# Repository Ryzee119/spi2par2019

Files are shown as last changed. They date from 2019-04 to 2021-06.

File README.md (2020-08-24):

# spi2par2019
  
## What is it?
This is a recreation of a legacy Original Xbox adaptor that allowed you to use extremely common and cheap HD44780 compliant character LCD displays with the Xenium modchip SPI interface. The legacy adaptor was called 'spi2par' and has long since been out of production and extremely hard to come by.

I have never had one either, so this design has been made from the ground up.

There are two PCB layouts in this repository:

1. More faithful to the legacy spi2par design.
2. An LCD backpack design that takes advantage of the standard pinout of most HD44780 LCD displays to minimise the amount of wiring needed.

These two layouts are shown in the below photo. The LCD backpack has two pin arrangements so can be used on the two common LCD pin header layouts as shown installed. The intent is to make this as open and easily accessible to anyone with minimal experience in soldering and programming.  
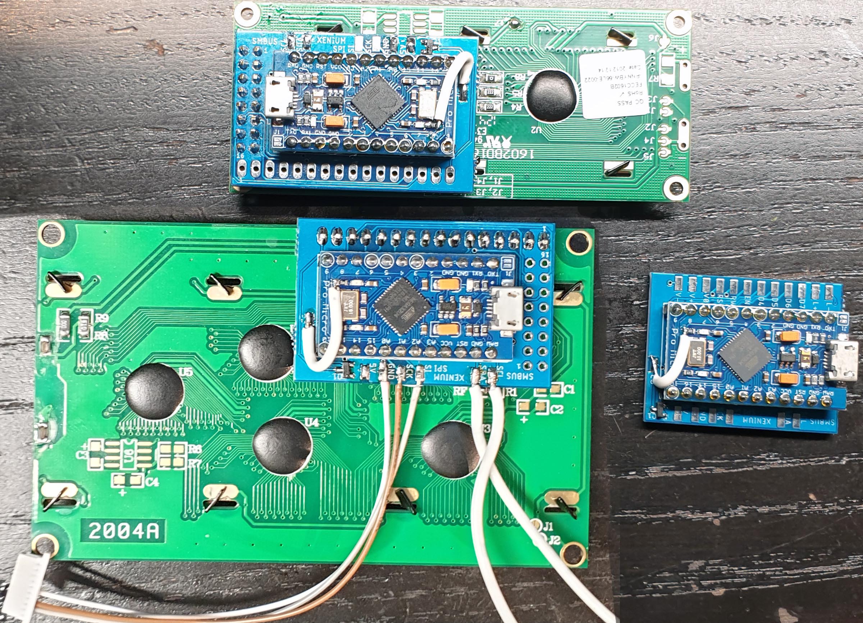
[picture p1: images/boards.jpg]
spi2par2019


## Features
1. Converts the Xenium SPI interface to HD44780 compliant parallel LCDs. These are extremely cheap and readily available LCD modules.
2. Software controllable brightness
3. Software controllable contrast
4. This feature never existed in the legacy. You can connect two additional wires to the motherboard LPC header, and the board will read fan speed and MB/CPU temperatures directly from the Xbox System Management bus. It will display and update this mid-game. Traditionally the LCD will just pause until you renter the dashboard.  Example below:  
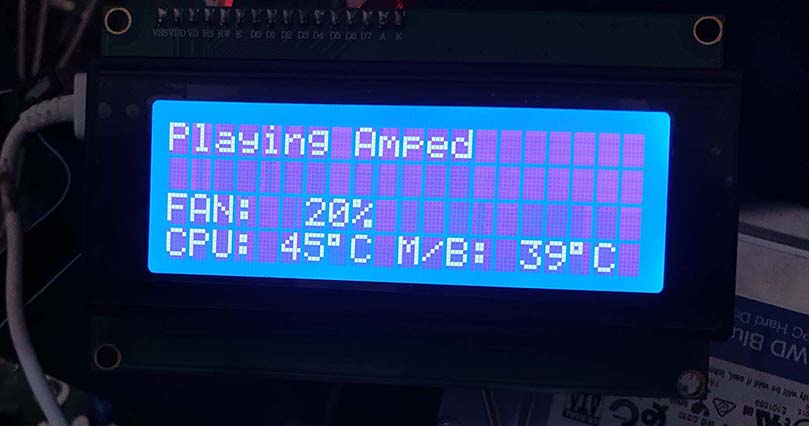
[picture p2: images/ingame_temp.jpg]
ingame


## Assembly and Materials Required
There is two ways you can do this. Option 1 is the intended way and has a PCB daughter board to make installation easier.  <br> The second option uses less components but requires more wiring.

#### Option 1 - Arduino module and PCB adaptor
The standard design

|Part|Qty | Possible Source|
|--|--|--|
| Ryzee119's spi2par2019 PCB |1| OSHPark (Bit expensive, 3 boards):  [spi2par2019backpack](https://oshpark.com/shared_projects/HGCRYTFI) OR<br> [spi2par2019faithful](https://oshpark.com/shared_projects/7YvM7Fwu)  <br>Or, Download the required zip file from the [Gerbers Folder](https://github.com/Ryzee119/spi2par2019/tree/master/hardware/gerbers) and upload the zip file to their online ordering service. Use the following PCB properties: <br> `2 layers, 45x30mm, 1.6mm thick, HASL, 1oz copper, no castellated holes`| 
| Arduino Pro Micro Leonardo 5V/16Mhz |1| [Any clones will work](https://www.aliexpress.com/item/New-Pro-Micro-for-arduino-ATmega32U4-5V-16MHz-Module-with-2-row-pin-header-For-Leonardo/32768308647.html). Make sure they're the 5V/16Mhz variant. | 
| N-Channel MOSFET 2N7002 SOT23 at position Q1| 1 |Find anywhere convenient <br> [Digikey](https://www.digikey.com.au/short/p4zbn8)<br> [Aliexpress](https://www.aliexpress.com/item/Free-Shipping-200PCS-2N7002-MOSFET-N-CH-60V-300MA-SOT-23/897983645.html) |
| JST SH1.0 10 pin 1mm connector (To connect to Xenium) | 1 |Digikey: [Connector](https://www.digikey.com.au/product-detail/en/jst-sales-america-inc/SHR-10V-S-B/455-1385-ND/759874) + 3x[Jumpers](https://www.digikey.com.au/product-detail/en/jst-sales-america-inc/ASSHSSH28K152/455-3076-ND/6009452) OR <br> Aliexpress: [Connector with Jumpers (Get the 10P one)](https://www.aliexpress.com/item/5PCS-100MM-SH-1-0-Wire-Cable-Connector-DIY-SH1-0-JST-2-3-4-5/32952366214.html)|
| General Hook-up Wire 26AWG or so| A metre or two |-|

#### Option 2 - Arduino module only
No extra PCB required, no backlight control, slightly harder soldering

|Part|Qty | Possible Source|
|--|--|--|
| Arduino Pro Micro Leonardo 5V/16Mhz |1| [Any clones will work](https://www.aliexpress.com/item/32768308647.html). Make sure they're the 5V/16Mhz variant. | 
| JST SH1.0 10 pin 1mm connector (To connect to Xenium) | 1 |Digikey: [Connector](https://www.digikey.com.au/product-detail/en/jst-sales-america-inc/SHR-10V-S-B/455-1385-ND/759874) + 3x[Jumpers](https://www.digikey.com.au/product-detail/en/jst-sales-america-inc/ASSHSSH28K152/455-3076-ND/6009452) OR <br> Aliexpress: [Connector with Jumpers (Get the 10P one)](https://www.aliexpress.com/item/32952366214.html)|
| General Hook-up Wire 26AWG or so| A metre or two |-|

## Programming
1. Clone this repository to your PC
2. Download then install the [Arduino IDE](https://www.arduino.cc/en/Main/Software).
3. Copy `spi2par2019` to your Sketch folder and open the `.ino` file.
4. Set the Board Type the `Arduino Leonardo` and the comport correctly.
5. Compile by clicking the tick in the top left.
5. Confirm it has compiled successfully from the console output.  
6. Connect a MicroUSB cable between the Arduino Module and the PC.   
7. Click the upload button and confirm successful. The LCD backlight should come on but no text will be displayed until connected to a Xenium or the Xbox SMBus.

## Installation
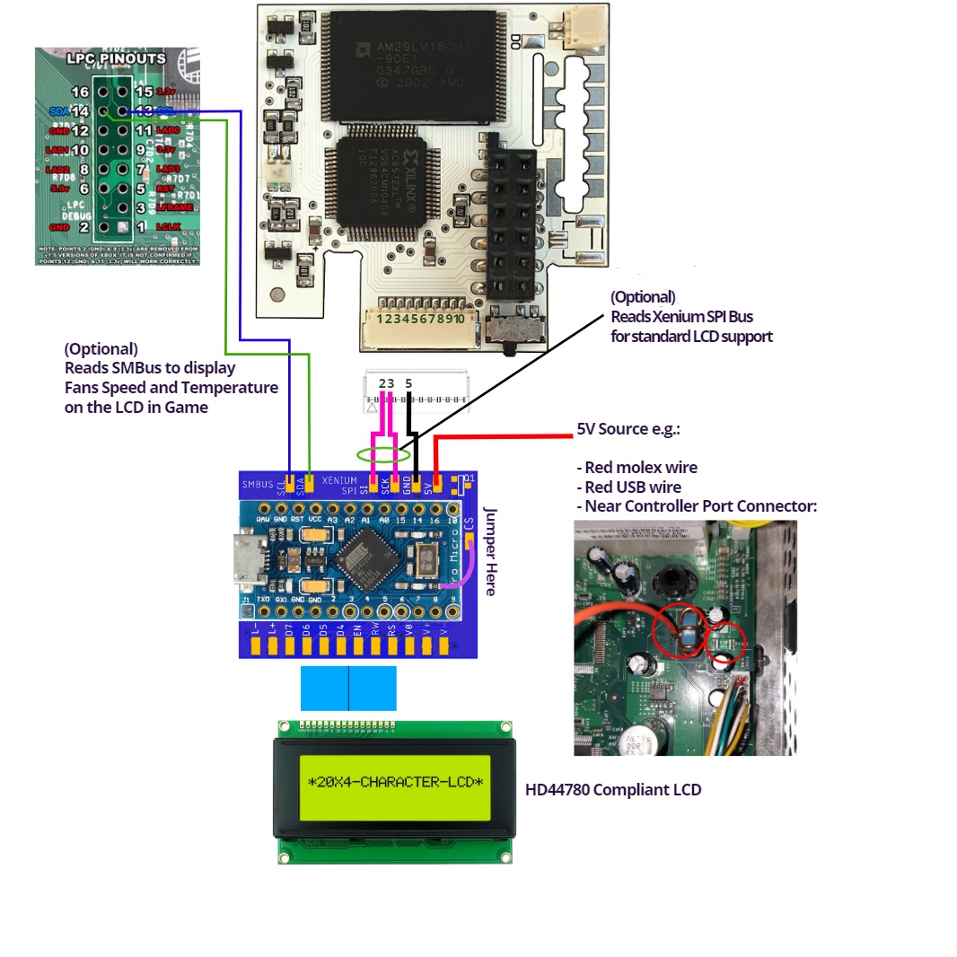
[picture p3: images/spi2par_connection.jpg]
spi2par2019 connection diagram


## Alternative Installation
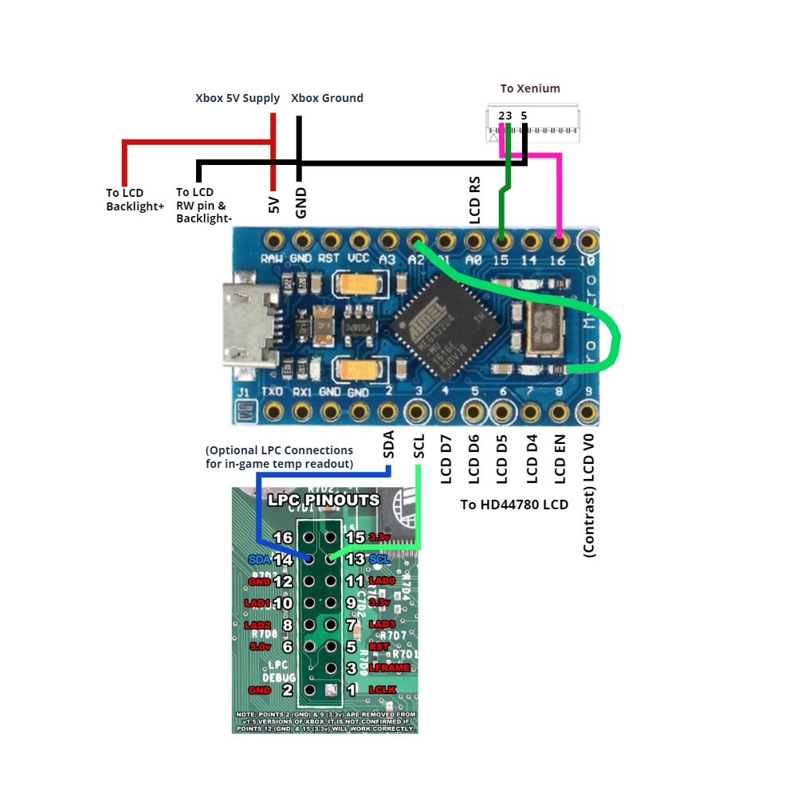
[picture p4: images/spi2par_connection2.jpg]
spi2par2019 connection diagram alt


## Further Setup
If using XBMC, there appears to be a bug in the way the large text is printed to the LCD screen when used with a Xenium. This can cause the LCD screen to stop working when the screen saver starts.
It is recommended to edit the /system/UserData/LCD.xml file and replace instances of `LCD.TimeWide21` or `LCD.TimeWide22` with something different. Perhaps `LCD.cputemperature` and `LCD.gputemperature` or if you want time, use the standard font (`System.Time`).

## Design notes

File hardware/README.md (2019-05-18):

# spi2par2019

All PCBs have been design using [Autodesk Eagle](https://www.autodesk.com/products/eagle/free-download) software.
This has been released as open source hardware released under the CERN Open Hardware Licence v1.2, <br><br><br>

CERN Open Hardware Licence v1.2 

Preamble

Through this CERN Open Hardware Licence ("CERN OHL") version 1.2, CERN
wishes to provide a tool to foster collaboration and sharing among
hardware designers.  The CERN OHL is copyright CERN. Anyone is welcome
to use the CERN OHL, in unmodified form only, for the distribution of
their own Open Hardware designs. Any other right is reserved. Release
of hardware designs under the CERN OHL does not constitute an
endorsement of the licensor or its designs nor does it imply any
involvement by CERN in the development of such designs.

1. Definitions

In this Licence, the following terms have the following meanings:
 
“Licence” means this CERN OHL.

“Documentation” means schematic diagrams, designs, circuit or circuit
board layouts, mechanical drawings, flow charts and descriptive text,
and other explanatory material that is explicitly stated as being made
available under the conditions of this Licence. The Documentation may
be in any medium, including but not limited to computer files and
representations on paper, film, or any other media.

“Documentation Location” means a location where the Licensor has
placed Documentation, and which he believes will be publicly
accessible for at least three years from the first communication to
the public or distribution of Documentation.

“Product” means either an entire, or any part of a, device built using
the Documentation or the modified Documentation.

“Licensee” means any natural or legal person exercising rights under
this Licence.

“Licensor” means any natural or legal person that creates or modifies
Documentation and subsequently communicates to the public and/ or
distributes the resulting Documentation under the terms and conditions
of this Licence.

A Licensee may at the same time be a Licensor, and vice versa. 

Use of the masculine gender includes the feminine and neuter genders
and is employed solely to facilitate reading.

2. Applicability

2.1. This Licence governs the use, copying, modification,
communication to the public and distribution of the Documentation, and
the manufacture and distribution of Products. By exercising any right
granted under this Licence, the Licensee irrevocably accepts these
terms and conditions.

2.2. This Licence is granted by the Licensor directly to the Licensee,
and shall apply worldwide and without limitation in time. The Licensee
may assign his licence rights or grant sub-licences.

2.3. This Licence does not extend to software, firmware, or code
loaded into programmable devices which may be used in conjunction with
the Documentation, the modified Documentation or with Products, unless
such software, firmware, or code is explicitly expressed to be subject
to this Licence. The use of such software, firmware, or code is
otherwise subject to the applicable licence terms and conditions.

3. Copying, modification, communication to the public and distribution
of the Documentation

3.1. The Licensee shall keep intact all copyright and trademarks
notices, all notices referring to Documentation Location, and all
notices that refer to this Licence and to the disclaimer of warranties
that are included in the Documentation. He shall include a copy
thereof in every copy of the Documentation or, as the case may be,
modified Documentation, that he communicates to the public or
distributes.

3.2. The Licensee may copy, communicate to the public and distribute
verbatim copies of the Documentation, in any medium, subject to the
requirements specified in section 3.1.

3.3. The Licensee may modify the Documentation or any portion thereof
provided that upon modification of the Documentation, the Licensee
shall make the modified Documentation available from a Documentation
Location such that it can be easily located by an original Licensor
once the Licensee communicates to the public or distributes the
modified Documentation under section 3.4, and, where required by
section 4.1, by a recipient of a Product. However, the Licensor shall
not assert his rights under the foregoing proviso unless or until a
Product is distributed.

3.4. The Licensee may communicate to the public and distribute the
modified Documentation (thereby in addition to being a Licensee also
becoming a Licensor), always provided that he shall:

a) comply with section 3.1;

b) cause the modified Documentation to carry prominent notices stating
that the Licensee has modified the Documentation, with the date and
description of the modifications;

c) cause the modified Documentation to carry a new Documentation
Location notice if the original Documentation provided for one;

d) make available the modified Documentation at the same level of
abstraction as that of the Documentation, in the preferred format for
making modifications to it (e.g. the native format of the CAD tool as
applicable), and in the event that format is proprietary, in a format
viewable with a tool licensed under an OSI-approved license if the
proprietary tool can create it; and

e) license the modified Documentation under the terms and conditions
of this Licence or, where applicable, a later version of this Licence
as may be issued by CERN.

3.5. The Licence includes a non-exclusive licence to those patents or
registered designs that are held by, under the control of, or
sub-licensable by the Licensor, to the extent necessary to make use of
the rights granted under this Licence. The scope of this section 3.5
shall be strictly limited to the parts of the Documentation or
modified Documentation created by the Licensor.

4. Manufacture and distribution of Products

4.1. The Licensee may manufacture or distribute Products always
provided that, where such manufacture or distribution requires a
licence under this Licence the Licensee provides to each recipient of
such Products an easy means of accessing a copy of the Documentation
or modified Documentation, as applicable, as set out in section 3.

4.2. The Licensee is invited to inform any Licensor who has indicated
his wish to receive this information about the type, quantity and
dates of production of Products the Licensee has (had) manufactured

5. Warranty and liability

5.1. DISCLAIMER – The Documentation and any modified Documentation are
provided "as is" and any express or implied warranties, including, but
not limited to, implied warranties of merchantability, of satisfactory
quality, non-infringement of third party rights, and fitness for a
particular purpose or use are disclaimed in respect of the
Documentation, the modified Documentation or any Product. The Licensor
makes no representation that the Documentation, modified
Documentation, or any Product, does or will not infringe any patent,
copyright, trade secret or other proprietary right. The entire risk as
to the use, quality, and performance of a Product shall be with the
Licensee and not the Licensor. This disclaimer of warranty is an
essential part of this Licence and a condition for the grant of any
rights granted under this Licence. The Licensee warrants that it does
not act in a consumer capacity.

5.2. LIMITATION OF LIABILITY – The Licensor shall have no liability
for direct, indirect, special, incidental, consequential, exemplary,
punitive or other damages of any character including, without
limitation, procurement of substitute goods or services, loss of use,
data or profits, or business interruption, however caused and on any
theory of contract, warranty, tort (including negligence), product
liability or otherwise, arising in any way in relation to the
Documentation, modified Documentation and/or the use, manufacture or
distribution of a Product, even if advised of the possibility of such
damages, and the Licensee shall hold the Licensor(s) free and harmless
from any liability, costs, damages, fees and expenses, including
claims by third parties, in relation to such use.

6. General

6.1. Except for the rights explicitly granted hereunder, this Licence
does not imply or represent any transfer or assignment of intellectual
property rights to the Licensee.

6.2. The Licensee shall not use or make reference to any of the names
(including acronyms and abbreviations), images, or logos under which
the Licensor is known, save in so far as required to comply with
section 3. Any such permitted use or reference shall be factual and
shall in no event suggest any kind of endorsement by the Licensor or
its personnel of the modified Documentation or any Product, or any
kind of implication by the Licensor or its personnel in the
preparation of the modified Documentation or Product.

6.3. CERN may publish updated versions of this Licence which retain
the same general provisions as this version, but differ in detail so
far this is required and reasonable. New versions will be published
with a unique version number.

6.4. This Licence shall terminate with immediate effect, upon written
notice and without involvement of a court if the Licensee fails to
comply with any of its terms and conditions, or if the Licensee
initiates legal action against Licensor in relation to this
Licence. Section 5 shall continue to apply.

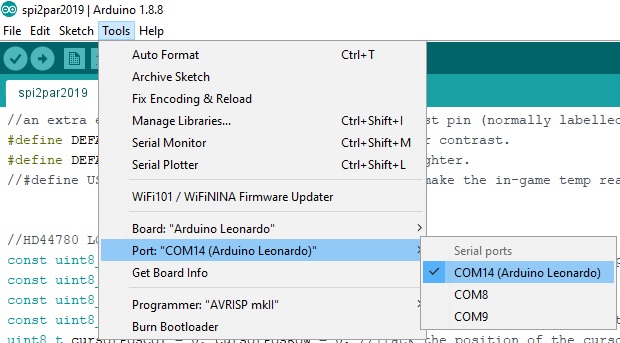
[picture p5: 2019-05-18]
images/prog7.jpg

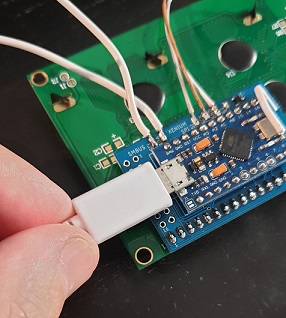
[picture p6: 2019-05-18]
images/prog4.jpg

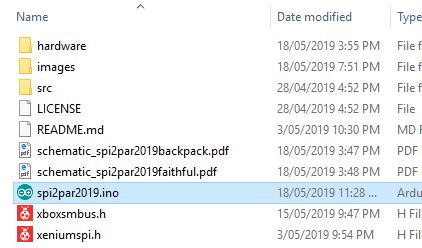
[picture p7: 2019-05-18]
images/prog1.jpg

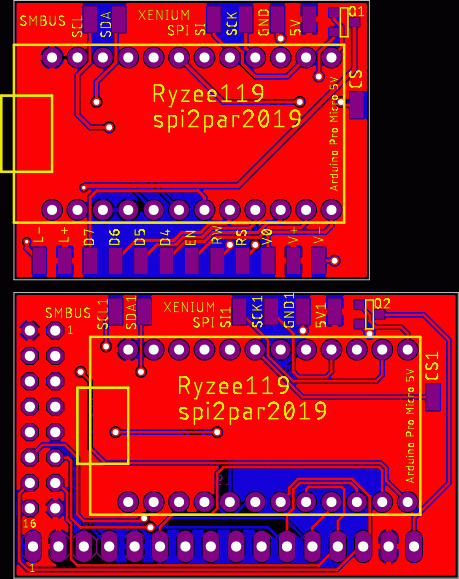
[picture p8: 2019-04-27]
images/gerbers.png

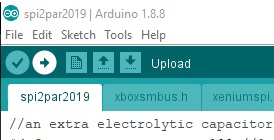
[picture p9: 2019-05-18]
images/prog5.jpg

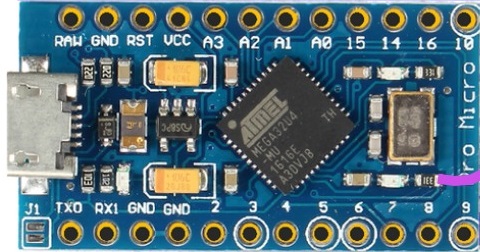
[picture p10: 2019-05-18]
images/arduino.jpg

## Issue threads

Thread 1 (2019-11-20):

ESP8266 possibility?

johngeffe, 2019-11-20:
Would you design a board that uses an ESP8266 (or similar) with antenna connection to open up even more possibilities for this?

Ryzee119, 2019-11-20:
Probably not anytime soon but it should be trivial for someone to port this code accordingly.
I am closing this issue as its not really an issue; but if you (or anyone) decide to fork this repo and put the work in I can provide help where I can

Closed 2019-11-20.

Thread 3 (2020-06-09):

Data error

jordinlockwood, 2020-06-09:
Hey using faithful design got power and display from open xenium but there seems to be a error with the data got d4-7 and all I’m getting is random characters moved d4 to 3 and got dat and time just can’t figure out how to get it all displayed properly

Closed 2020-06-09.

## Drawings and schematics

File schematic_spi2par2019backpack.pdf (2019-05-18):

A

A

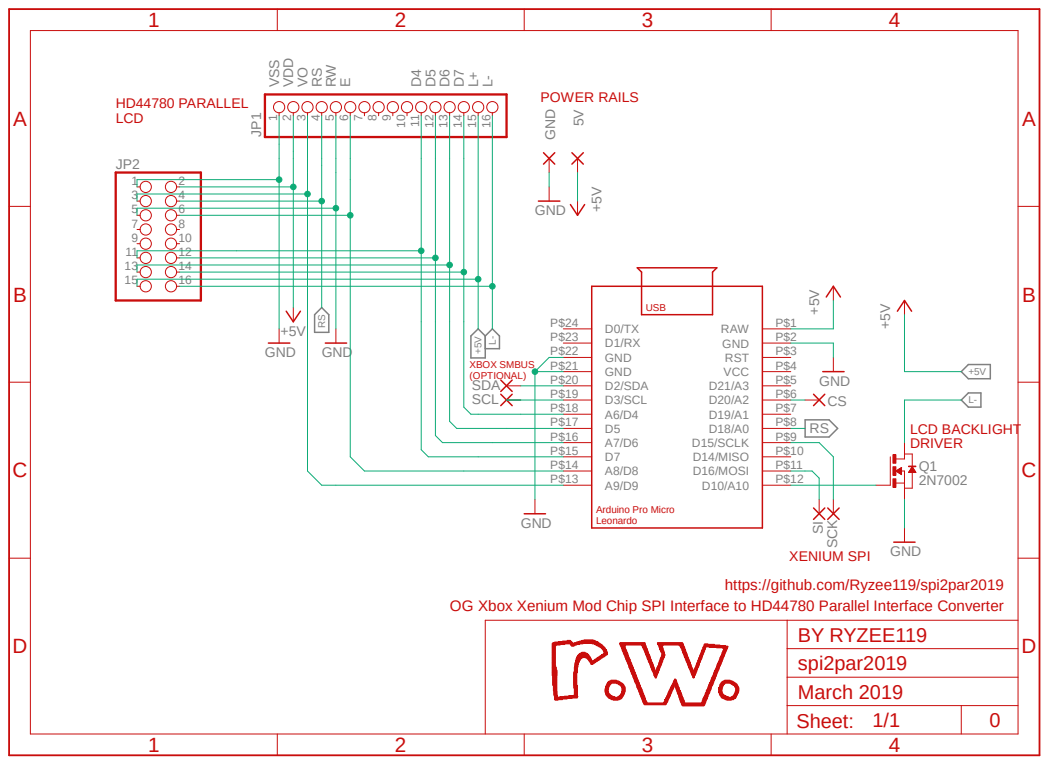
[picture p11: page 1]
GND; RAW; RST; VCC; D15/SCLK; D14/MISO; D16/MOSI; D3/SCL P$19; D2/SDA P$20; GND P$21; GND P$22; Q1 SI SCK GND; SCL; SDA; spi2par2019 March 2019; BY RYZEE119; HD44780 PARALLEL LCD; POWER RAILS; LCD BACKLIGHT DRIVER; XENIUM SPI; XBOX SMBUS (OPTIONAL); USB; Sheet:

VSS VDD VORSRW

Arduino Pro Micro
Leonardo

https://github.com/Ryzee119/spi2par2019

OG Xbox Xenium Mod Chip SPI Interface to HD44780 Parallel Interface Converter

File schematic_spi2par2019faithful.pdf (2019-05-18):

A

A

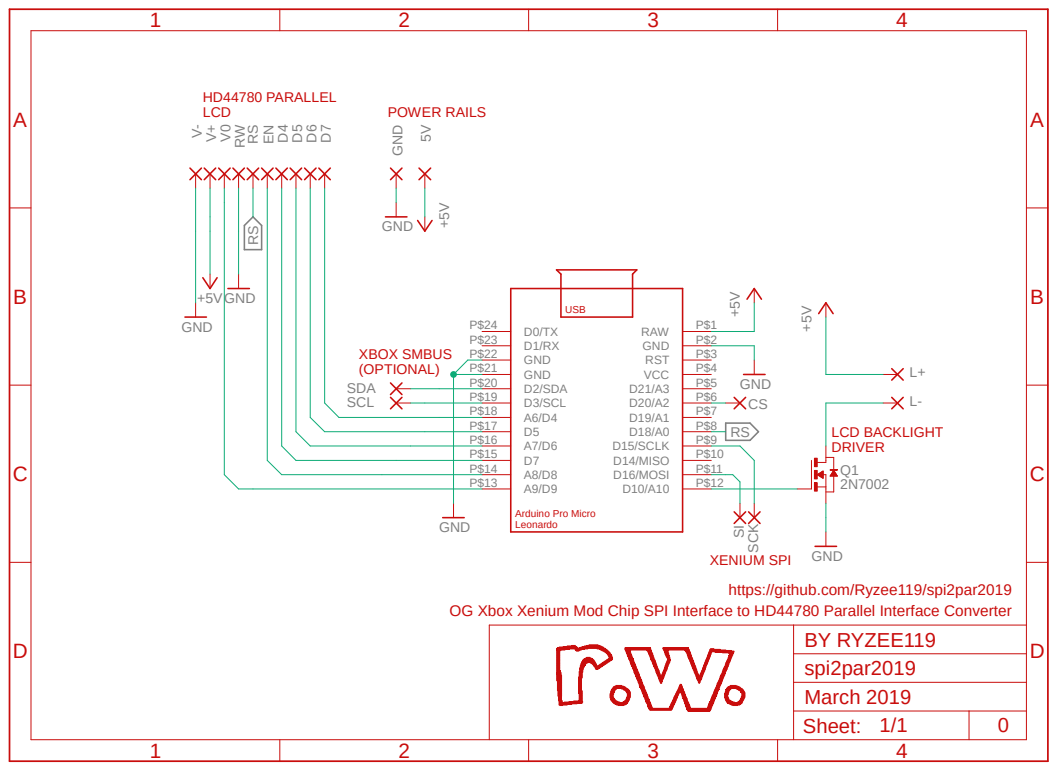
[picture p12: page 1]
GND; RAW; RST; VCC; D15/SCLK; D14/MISO; D16/MOSI; D3/SCL P$19; D2/SDA P$20; GND P$21; GND P$22; Q1 SI SCK GNDRSEND⁴ D⁵ D⁶ D⁷; SCL; SDA RS; spi2par2019 March 2019; BY RYZEE119; HD44780 PARALLEL; LCD; POWER RAILS; LCD BACKLIGHT DRIVER; XBOX SMBUS (OPTIONAL); USB; Sheet:

Arduino Pro Micro
Leonardo

XENIUM SPI
https://github.com/Ryzee119/spi2par2019

OG Xbox Xenium Mod Chip SPI Interface to HD44780 Parallel Interface Converter

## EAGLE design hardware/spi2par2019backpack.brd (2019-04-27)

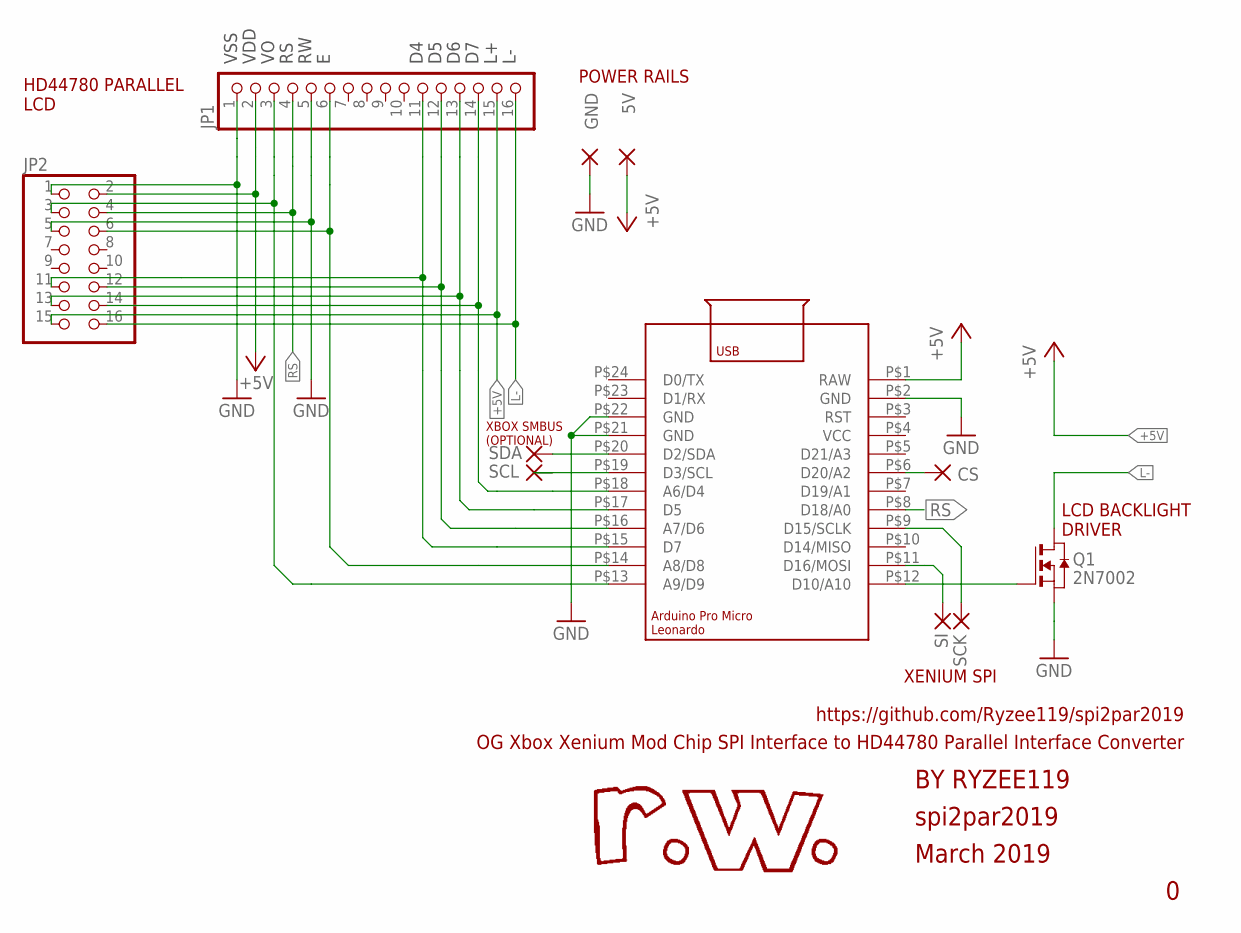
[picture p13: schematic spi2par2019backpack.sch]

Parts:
5V: WIREPADSMD1,27-254; SMD1,27-2,54
CS: WIREPADSMD1,27-254; SMD1,27-2,54
GND: WIREPADSMD1,27-254; SMD1,27-2,54
JP1: PINHD-1X16; 1X16
JP2: PINHD-2X8; 2X08
Q1: 2N70026Ω; SOT-23
SCK: WIREPADSMD1,27-254; SMD1,27-2,54
SCL: WIREPADSMD1,27-254; SMD1,27-2,54
SDA: WIREPADSMD1,27-254; SMD1,27-2,54
SI: WIREPADSMD1,27-254; SMD1,27-2,54
U1: ARDUINO_LEONARDO_MICRO

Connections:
+5V: 5V.1, JP1.2, JP1.15, JP2.2, JP2.15, U1.P$1 (RAW)
D4: JP1.11, JP2.11, U1.P$15 (D7)
D5: JP1.12, JP2.12, U1.P$16 (A7/D6)
D6: JP1.13, JP2.13, U1.P$17 (D5)
D7: JP1.14, JP2.14, U1.P$18 (A6/D4)
E: JP1.6, JP2.6, U1.P$14 (A8/D8)
GND: GND.1, JP1.1, JP1.5, JP2.1, JP2.5, Q1.2 (S), U1.P$2 (GND), U1.P$21 (GND), U1.P$22 (GND)
L-: JP1.16, JP2.16, Q1.1 (D)
unnamed: SCL.1, U1.P$19 (D3/SCL)
unnamed: CS.1, U1.P$6 (D20/A2)
unnamed: SCK.1, U1.P$9 (D15/SCLK)
unnamed: SI.1, U1.P$11 (D16/MOSI)
unnamed: Q1.3 (G), U1.P$12 (D10/A10)
unnamed: SDA.1, U1.P$20 (D2/SDA)
RS: JP1.4, JP2.4, U1.P$8 (D18/A0)
VO: JP1.3, JP2.3, U1.P$13 (A9/D9)

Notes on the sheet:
spi2par2019
March 2019
BY RYZEE119
OG Xbox Xenium Mod Chip SPI Interface to HD44780 Parallel Interface Converter
https://github.com/Ryzee119/spi2par2019
HD44780 PARALLEL LCD
POWER RAILS
LCD BACKLIGHT DRIVER
XENIUM SPI
XBOX SMBUS (OPTIONAL)
2N7002
VSS
VDD

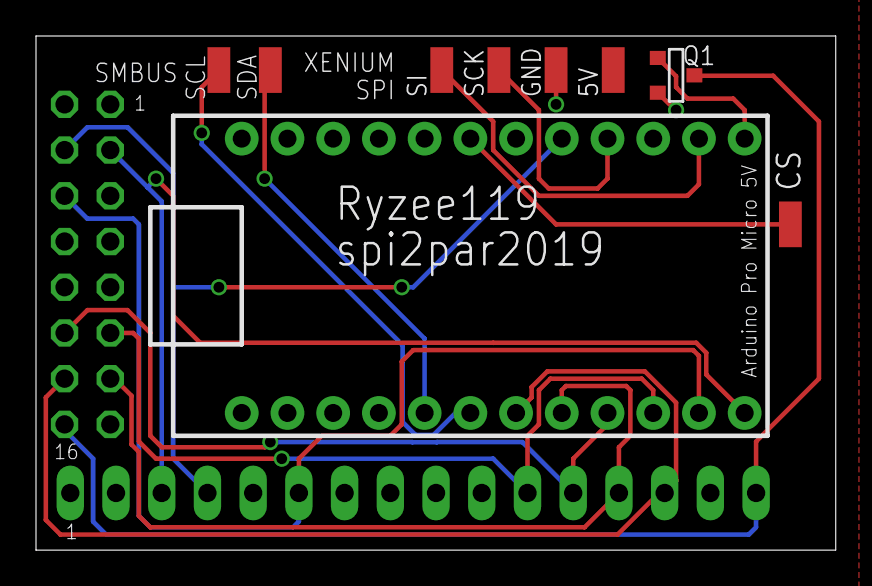
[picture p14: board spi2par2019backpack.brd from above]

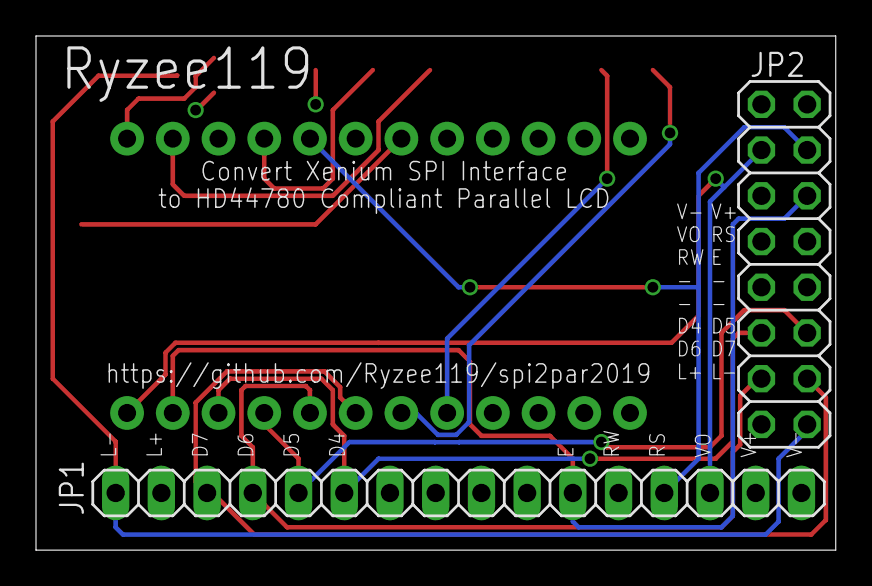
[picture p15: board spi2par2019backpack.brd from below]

Board: 2 copper layers, 44.4 x 28.6 mm, 11 parts (2 on the bottom side), 16 nets.

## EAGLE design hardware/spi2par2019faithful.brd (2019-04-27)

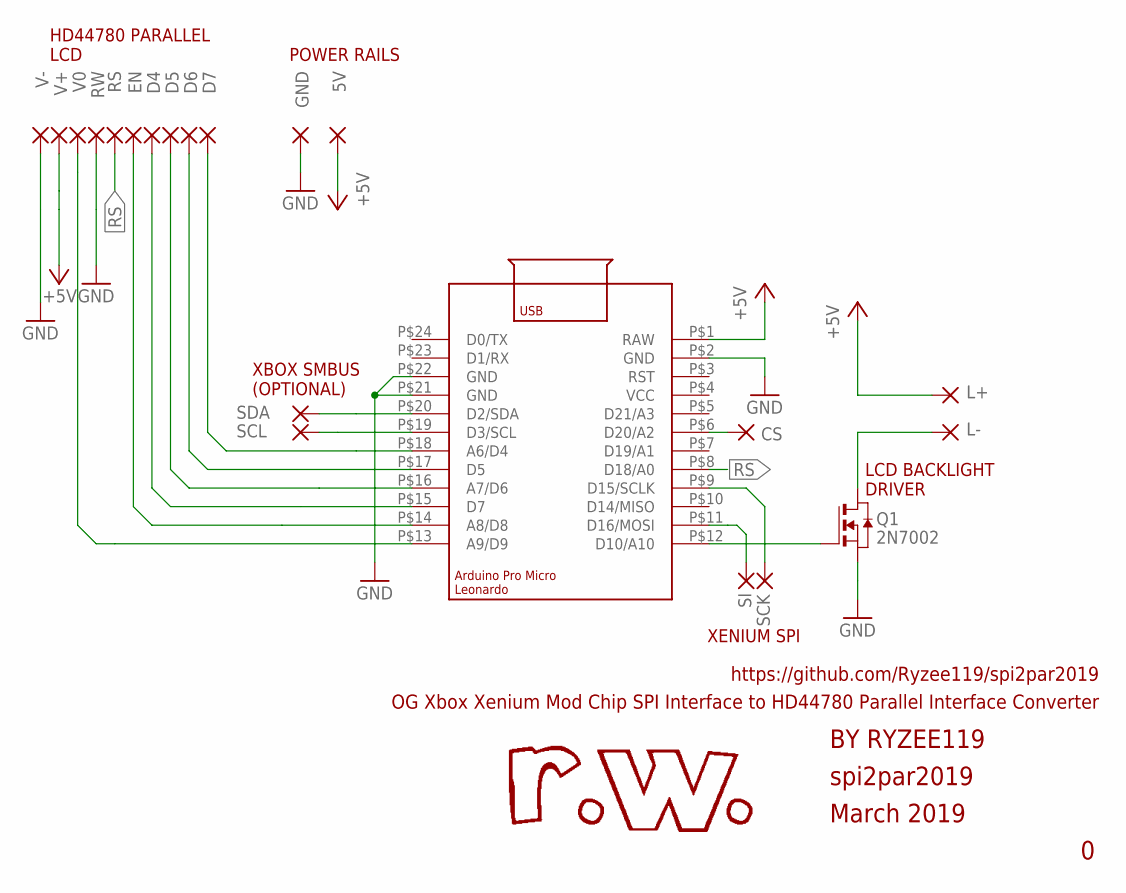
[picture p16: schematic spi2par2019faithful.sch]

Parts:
5V: WIREPADSMD1,27-254; SMD1,27-2,54
CS: WIREPADSMD1,27-254; SMD1,27-2,54
D4, D5, D6, D7: WIREPADSMD1,27-254; SMD1,27-2,54
EN: WIREPADSMD1,27-254; SMD1,27-2,54
GND: WIREPADSMD1,27-254; SMD1,27-2,54
L+: WIREPADSMD1,27-254; SMD1,27-2,54
L-: WIREPADSMD1,27-254; SMD1,27-2,54
Q1: 2N70026Ω; SOT-23
RS: WIREPADSMD1,27-254; SMD1,27-2,54
RW: WIREPADSMD1,27-254; SMD1,27-2,54
SCK: WIREPADSMD1,27-254; SMD1,27-2,54
SCL: WIREPADSMD1,27-254; SMD1,27-2,54
SDA: WIREPADSMD1,27-254; SMD1,27-2,54
SI: WIREPADSMD1,27-254; SMD1,27-2,54
U1: ARDUINO_LEONARDO_MICRO
V0: WIREPADSMD1,27-254; SMD1,27-2,54
V+: WIREPADSMD1,27-254; SMD1,27-2,54
V-: WIREPADSMD1,27-254; SMD1,27-2,54

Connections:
+5V: 5V.1, L+.1, U1.P$1 (RAW), V+.1
GND: GND.1, Q1.2 (S), RW.1, U1.P$2 (GND), U1.P$21 (GND), U1.P$22 (GND), V-.1
unnamed: SCL.1, U1.P$19 (D3/SCL)
unnamed: CS.1, U1.P$6 (D20/A2)
unnamed: SCK.1, U1.P$9 (D15/SCLK)
unnamed: SI.1, U1.P$11 (D16/MOSI)
unnamed: D7.1, U1.P$18 (A6/D4)
unnamed: D6.1, U1.P$17 (D5)
unnamed: D5.1, U1.P$16 (A7/D6)
unnamed: D4.1, U1.P$15 (D7)
unnamed: EN.1, U1.P$14 (A8/D8)
unnamed: Q1.3 (G), U1.P$12 (D10/A10)
unnamed: U1.P$13 (A9/D9), V0.1
unnamed: L-.1, Q1.1 (D)
unnamed: SDA.1, U1.P$20 (D2/SDA)
RS: RS.1, U1.P$8 (D18/A0)

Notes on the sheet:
spi2par2019
March 2019
BY RYZEE119
OG Xbox Xenium Mod Chip SPI Interface to HD44780 Parallel Interface Converter
https://github.com/Ryzee119/spi2par2019
HD44780 PARALLEL LCD
POWER RAILS
LCD BACKLIGHT DRIVER
XENIUM SPI
XBOX SMBUS (OPTIONAL)
2N7002

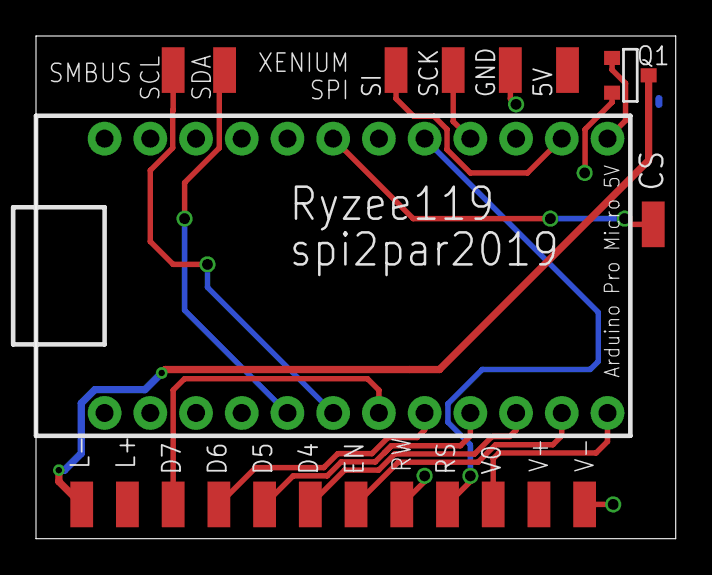
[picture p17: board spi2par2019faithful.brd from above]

Board: 2 copper layers, 35.5 x 27.9 mm, 21 parts (0 on the bottom side), 16 nets.

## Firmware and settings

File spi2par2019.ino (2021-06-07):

#include "xeniumspi.h"
#include "xboxsmbus.h"
#include "src/SMWire/SMWire.h"
#include <LiquidCrystal.h>

//Some screens like difference contrast values. So I couldn't really set a good default value
//Play around and adjust to suit your screen. If you have flickering issues, it may help to solder
//an extra electrolytic capacitor between the contrast pin (normally labelled 'V0') and GND.
#define DEFAULT_CONTRAST 100 //0-255. Lower is higher contrast.
#define DEFAULT_BACKLIGHT 255 //0-255. Higher is brighter.
//#define USE_FAHRENHEIT 1 //Uncomment this line to make the in-game temp readouts display in Fahrenheit.

//Use the following lines to set the LCD display size; currently only displays of 20/16 columns and 4 rows are supported.
//16 column displays will have issues with the dashboard display as these are all expecting 20 column displays.
#define LCD_ROW 4
#define LCD_COL 20

#if (LCD_COL == 16)
        #define tempDisplayF "CPU:%3u%c MB:%3u%c"
        #define tempDisplayC "CPU:%3u%c MB:%3u%c"
        #define tenEightyI "1080i "
        #define sevenTwentyP "720p "
        #define fourEightyI "480i "
        #define fourEightyP "480p "
        #define fanSpeed "FAN: %3u%%  "
#else
        #define tempDisplayF "CPU:%3u%cF M/B:%3u%cF "
        #define tempDisplayC "CPU:%3u%cC M/B:%3u%cC "
        #define tenEightyI " 1080i  "
        #define sevenTwentyP " 720p   "
        #define fourEightyI " 480i    "
        #define fourEightyP " 480p    "
        #define fanSpeed "FAN: %3u%%   "

#endif


//HD44780 LCD Setup
const uint8_t rs = 18, en = 8, d4 = 7, d5 = 6, d6 = 5, d7 = 4; //HD44780 compliant LCD display pin numbers
const uint8_t ss_in = 17, miso = 14, mosi = 16, sck = 15, ss_out = A2; //SPI pin numbers, ss_in is the CS for the slave. As Xenium doesn't seem to use CS, ss_out is connected to ss_in on the PCB to manually trigger CS.
const uint8_t i2c_sda = 2, i2c_scl = 3; //i2c pins for SMBus
const uint8_t backlightPin = 10, contrastPin = 9; //Pin nubmers for backlight and contrast. Must be PWM enabled
uint8_t cursorPosCol = 0, cursorPosRow = 0; //Track the position of the cursor
uint8_t wrapping = 0, scrolling = 0; //Xenium spi command toggles for the lcd screen.
LiquidCrystal hd44780(rs, en, d4, d5, d6, d7); //Constructor for the LCD.


//SPI Data
int16_t RxQueue[256]; //Input FIFO buffer for raw SPI data from Xenium
uint8_t QueuePos; //Tracks the current position in the FIFO queue that is being processed
uint8_t QueueRxPos; //Tracks the current position in the FIFO queue of the unprocessed input data (raw realtime SPI data)
uint8_t SPIState; //SPI State machine flag to monitor the SPI bus state can = SPI_ACTIVE, SPI_IDLE, SPI_SYNC, SPI_WAIT
uint32_t SPIIdleTimer; //Tracks how long the SPI bus has been idle for



//I2C Bus
uint32_t SMBusTimer; //Timer used to trigger SMBus reads
uint8_t i2cCheckCount = 0;      //Tracks what check we're up to of the i2c bus busy state
uint8_t I2C_BUSY_CHECKS = 5;  //To ensure we don't interfere with the actual Xbox's SMBus activity, we check the bus for activity for sending.


//SPI Bus Receiver Interrupt Routine
ISR (SPI_STC_vect) {
  RxQueue[QueueRxPos] = SPDR;
  QueueRxPos++; //This is an unsigned 8 bit variable, so will reset back to 0 after 255 automatically
  SPIState = SPI_ACTIVE;

}

void setup() {
  pinMode(ss_out, OUTPUT);
  digitalWrite(ss_out, HIGH); //Force SPI CS signal high while we setup
  Serial.begin(9600);
  delay(5);
  for (uint8_t i = 0; i < 8; i++) {
    delay(1);
    hd44780.createChar(i, &chars[i][0]);
  }

  hd44780.begin(LCD_COL, LCD_ROW);
  hd44780.noCursor();

  memset(RxQueue, -1, 256);


  //I put my logic analyser on the Xenium SPI bus to confirm the bus properties.
  //The master clocks at ~16kHz. SPI Clock is high when inactive, data is valid on the trailing edge (CPOL/CPHA=1. Also known as SPI mode 3)
  SPCR |= _BV(SPE);   //Turn on SPI. We don't set the MSTR bit so it's slave.
  SPCR |= _BV(SPIE);  //Enable to SPI Interrupt Vector
  SPCR |= _BV(CPOL);  //SPI Clock is high when inactive
  SPCR |= _BV(CPHA);  //Data is Valid on Clock Trailing Edge

  Wire.begin(0xDD); //Random address that is different from existing bus devices.
  TWBR = ((F_CPU / 72000) - 16) / 2; //Change I2C frequency closer to OG Xbox SMBus speed. ~72kHz Not compulsory really, but a safe bet

  analogWrite(backlightPin, DEFAULT_BACKLIGHT); //0-255 Higher number is brighter.
  analogWrite(contrastPin, DEFAULT_CONTRAST); //0-255 Lower number is higher contrast

  //Speed up PWM frequency. Gets rid of flickering
  TCCR1B &= 0b11111000;
  TCCR1B |= (1 << CS00); //Change Timer Prescaler for PWM
  hd44780.setCursor(0, 0);

  //delay(250);
  uint32_t spiReadyTimer = millis();
  bool spiReady = false;

  //Hold until spi bus is ready
  while (!spiReady) {
    if (digitalRead(sck) == 0) {
      spiReadyTimer = millis();
    }
    //SPI Clock high for 100ms
    else if (millis() - spiReadyTimer > 100) {
      spiReady = true;
    }
  }
  digitalWrite(ss_out, LOW); //SPI Slave is ready to receive data

}


void loop() {
  //SPI to Parallel Conversion State Machine
  //One completion of processing command, set the buffer data value to -1
  //to indicate processing has been completed.


  if (QueueRxPos != QueuePos) {
    switch (RxQueue[(uint8_t)QueuePos]) {
      case -1:
        //No action required.
        break;

      case XeniumCursorHome:
        cursorPosRow = 0;
        cursorPosCol = 0;
        hd44780.setCursor(cursorPosCol, cursorPosRow);
        completeCommand(&RxQueue[(uint8_t)QueuePos]);
        break;

      case XeniumHideDisplay:
        hd44780.noDisplay();
        completeCommand(&RxQueue[(uint8_t)QueuePos]);
        break;

      case XeniumShowDisplay:
        hd44780.display();
        completeCommand(&RxQueue[(uint8_t)QueuePos]);
        break;

      case XeniumHideCursor:
        hd44780.noCursor();
        completeCommand(&RxQueue[(uint8_t)QueuePos]);
        break;

      case XeniumShowUnderLineCursor:
      case XeniumShowBlockCursor:
      case XeniumShowInvertedCursor:
        hd44780.cursor();
        hd44780.blink();
        completeCommand(&RxQueue[(uint8_t)QueuePos]);
        break;

      case XeniumBackspace:
        if (cursorPosCol > 0) {
          cursorPosCol--;
          hd44780.setCursor(cursorPosCol, cursorPosRow);
          hd44780.print(" ");
          hd44780.setCursor(cursorPosCol, cursorPosRow);
        }
        completeCommand(&RxQueue[(uint8_t)QueuePos]);
        break;

      case XeniumLineFeed: //Move Cursor down one row, but keep column
        if (cursorPosRow < LCD_ROW - 1) {
          cursorPosRow++;
          hd44780.setCursor(cursorPosCol, cursorPosRow);
        }
        completeCommand(&RxQueue[(uint8_t)QueuePos]);
        break;

      case XeniumDeleteInPlace: //Delete the character at the current cursor position
        hd44780.print(" ");
        hd44780.setCursor(cursorPosCol, cursorPosRow);
        completeCommand(&RxQueue[(uint8_t)QueuePos]);
        break;

      case XeniumFormFeed: //Formfeed just clears the screen and resets the cursor.
        hd44780.clear();
        cursorPosRow = 0;
        cursorPosCol = 0;
        hd44780.setCursor(cursorPosCol, cursorPosRow);
        completeCommand(&RxQueue[(uint8_t)QueuePos]);
        break;

      case XeniumCarriageReturn: //Carriage returns moves the cursor to the start of the current line
        cursorPosCol = 0;
        hd44780.setCursor(cursorPosCol, cursorPosRow);
        completeCommand(&RxQueue[(uint8_t)QueuePos]);
        break;

      case XeniumSetCursorPosition: //Sets the row and column of cursor. The following two bytes are the row and column.
        if (RxQueue[(uint8_t)(QueuePos + 2)] != -1) {
          uint8_t col = RxQueue[(uint8_t)(QueuePos + 1)]; //Column
          uint8_t row = RxQueue[(uint8_t)(QueuePos + 2)]; //Row
          if (col < LCD_COL && row < LCD_ROW) {
            hd44780.setCursor(col, row);
            cursorPosCol = col, cursorPosRow = row;
          }
          completeCommand(&RxQueue[(uint8_t)QueuePos]);
          completeCommand(&RxQueue[(uint8_t)(QueuePos + 1)]);
          completeCommand(&RxQueue[(uint8_t)(QueuePos + 2)]);
        }
        break;

      case XeniumSetBacklight:
        //The following byte after the backlight command is the brightness value
        //Value is 0-100 for the backlight brightness. 0=OFF, 100=ON
        //AVR PWM Output is 0-255. We multiply by 2.55 to match AVR PWM range.
        if (RxQueue[(uint8_t)(QueuePos + 1)] != -1) { //ensure the command is complete
          uint8_t brightness = RxQueue[(uint8_t)(QueuePos + 1)];
          if (brightness >= 0 && brightness <= 100) {
            analogWrite(backlightPin, (uint8_t)(brightness * 2.55f)); //0-255 for AVR PWM
          }
          completeCommand(&RxQueue[(uint8_t)QueuePos]);
          completeCommand(&RxQueue[(uint8_t)(QueuePos + 1)]);
        }
        break;

      case XeniumSetContrast:
        //The following byte after the contrast command is the contrast value
        //Value is 0-100 0=Very Light, 100=Very Dark
        //AVR PWM Output is 0-255. We multiply by 2.55 to match AVR PWM range.
        if (RxQueue[(uint8_t)(QueuePos + 1)] != -1) { //ensure the command is complete
          uint8_t contrastValue = 100 - RxQueue[(uint8_t)(QueuePos + 1)]; //needs to convert to 100-0 instead of 0-100.
          if (contrastValue >= 0 && contrastValue <= 100) {
            analogWrite(contrastPin, (uint8_t)(contrastValue * 2.55f));
          }
          completeCommand(&RxQueue[(uint8_t)QueuePos]);
          completeCommand(&RxQueue[(uint8_t)(QueuePos + 1)]);
        }
        break;

      case XeniumReboot:
        cursorPosRow = 0;
        cursorPosCol = 0;
        hd44780.begin(LCD_COL, LCD_ROW);
        completeCommand(&RxQueue[(uint8_t)QueuePos]);
        break;

      case XeniumCursorMove:
        //The following 2 bytes after the initial command is the direction to move the cursor
        //offset+1 is always 27, offset+2 is 65,66,67,68 for Up,Down,Right,Left
        if (RxQueue[(uint8_t)(QueuePos + 1)] == 27 &&
            RxQueue[(uint8_t)(QueuePos + 2)] != -1) {

          switch (RxQueue[(uint8_t)(QueuePos + 2)]) {
            case 65: //UP
              if (cursorPosRow > 0) cursorPosRow--;
              break;
            case 66: //DOWN
              if (cursorPosRow < (LCD_ROW - 1) ) cursorPosRow++;
              break;
            case 67: //RIGHT
              if (cursorPosCol < (LCD_COL - 1)) cursorPosCol++;
              break;
            case 68: //LEFT
              if (cursorPosCol > 0) cursorPosCol--;
              break;
            default:
              //Error: Invalid cursor direction
              break;
          }
          hd44780.setCursor(cursorPosCol, cursorPosRow);
          completeCommand(&RxQueue[(uint8_t)QueuePos]);
          completeCommand(&RxQueue[(uint8_t)(QueuePos + 1)]);
          completeCommand(&RxQueue[(uint8_t)(QueuePos + 2)]);
        }
        break;

      //Scrolling and wrapping commands are handled here.
      //The flags are toggled, but are not implemented properly yet
      //My testing seems to indicates it's not really needed.
      case XeniumWrapOff:
        wrapping = 0;
        completeCommand(&RxQueue[(uint8_t)QueuePos]);
        break;

      case XeniumWrapOn:
        wrapping = 1;
        completeCommand(&RxQueue[(uint8_t)QueuePos]);
        break;

      case XeniumScrollOff:
        scrolling = 0;
        completeCommand(&RxQueue[(uint8_t)QueuePos]);
        break;

      case XeniumScrollOn:
        scrolling = 1;
        completeCommand(&RxQueue[(uint8_t)QueuePos]);
        break;

      case  32 ... 255: //Just an ASCII character
        if (cursorPosCol < LCD_COL) {
          hd44780.setCursor(cursorPosCol, cursorPosRow);
          hd44780.write((char)RxQueue[(uint8_t)QueuePos]);
          cursorPosCol++;
        }
        completeCommand(&RxQueue[(uint8_t)QueuePos]);
        break;

      //Not implemented. Dont seem to be used anyway.
      case XeniumLargeNumber:
      case XeniumDrawBarGraph:
      case XeniumModuleConfig:
      case XeniumCustomCharacter:
      default:
        //hd44780.setCursor(0, 0);
        //Serial.print("Not implemented ");
        //Serial.print(RxQueue[(uint8_t)QueuePos], DEC);
        //Serial.print("\r\n");
        //hd44780.setCursor(cursorPosCol, cursorPosRow);
        completeCommand(&RxQueue[(uint8_t)QueuePos]);
        break;
    }

    if (RxQueue[(uint8_t)QueuePos] == -1) {
      QueuePos = (uint8_t)(QueuePos + 1);
    }

  }

  /* State machine to monitor the SPI Bus idle state */
  /* State machine to monitor the SPI Bus idle state */
  //If SPI bus has been idle pulse the CS line to resync the bus.
  //Xenium SPI bus doesnt use a Chip select line to resync the bus so this is a bit hacky, but improved reliability
  if (SPIState == SPI_ACTIVE) {
    SPIState = SPI_IDLE;
    SPIIdleTimer = millis();

  } else if (SPIState == SPI_IDLE && (millis() - SPIIdleTimer) > 100) {
    SPIState = SPI_SYNC;
    digitalWrite(ss_out, HIGH);
    SPIIdleTimer = millis();

  } else if (SPIState == SPI_SYNC && (millis() - SPIIdleTimer) > 25) {
    digitalWrite(ss_out, LOW);
    SPIState = SPI_WAIT;
  }


  /* Read data from Xbox System Management Bus */
  //Check that i2cBus is free, it has been atleast 2 seconds since last call,
  //and the SPI Bus has been idle for >10 seconds (i.e in a game or app that doesnt support LCD)
  if (i2cBusy() == 0 &&
      (millis() - SMBusTimer)   > 2000 &&
      (millis() - SPIIdleTimer) > 10000){ 

    char rxBuffer[20];    //Raw data received from SMBus
    char lineBuffer[LCD_COL]; //Fomatted data for printing to LCD 


    //Read the current fan speed directly from the SMC and print to LCD
    if (readSMBus(SMC_ADDRESS, SMC_FANSPEED, &rxBuffer[0], 1) == 0) {
      if (rxBuffer[0] >= 0 && rxBuffer[0] <= 50) { //Sanity check. Number should be 0-50
        snprintf(lineBuffer, sizeof lineBuffer, "FAN: %3u%% ", rxBuffer[0] * 2);
        hd44780.setCursor(0, 2); //Write to 3rd row of hd44780. 0=Row 1, 2=Row 3
        hd44780.print(lineBuffer);
      }
    }


    //Read Focus Chip to determine video resolution (for Version 1.4 console only)
    if (readSMBus(FOCUS_ADDRESS, FOCUS_PID, &rxBuffer[0], 2) == 0) {
      uint16_t PID = ((uint16_t)rxBuffer[1]) << 8 | rxBuffer[0];
      if (PID == 0xFE05) {
        readSMBus(FOCUS_ADDRESS, FOCUS_VIDCNTL, &rxBuffer[0], 2);
        uint16_t VID_CNTL0 = ((uint16_t)rxBuffer[1]) << 8 | rxBuffer[0];

        if (VID_CNTL0 & FOCUS_VIDCNTL_VSYNC5_6 && VID_CNTL0 & FOCUS_VIDCNTL_INT_PROG) {
          //Must be HDTV, interlaced (1080i)
          hd44780.print(tenEightyI);

        } else if (VID_CNTL0 & FOCUS_VIDCNTL_VSYNC5_6 && !(VID_CNTL0 & FOCUS_VIDCNTL_INT_PROG)) {
          //Must be HDTV, Progressive 720p
          hd44780.print(sevenTwentyP);

        } else if (!(VID_CNTL0 & FOCUS_VIDCNTL_VSYNC5_6) && VID_CNTL0 & FOCUS_VIDCNTL_INT_PROG) {
          //Must be SDTV, interlaced 480i
          hd44780.print(fourEightyI);

        } else if (!(VID_CNTL0 & FOCUS_VIDCNTL_VSYNC5_6) && !(VID_CNTL0 & FOCUS_VIDCNTL_INT_PROG)) {
          //Must be SDTV, Progressive 480p
          hd44780.print(fourEightyP);

        } else {
          hd44780.print(VID_CNTL0, HEX); //Not sure what it is. Print the code.
        }
      }

      //Read Conexant Chip to determine video resolution (for Version 1.0 to 1.3 console only)
    } else if (readSMBus(CONEX_ADDRESS, CONEX_2E, &rxBuffer[0], 1) == 0) {
      if ((uint8_t)(rxBuffer[0] & 3) == 3) {
        //Must be 1080i
        hd44780.print(tenEightyI);

      } else if ((uint8_t)(rxBuffer[0] & 3) == 2) {
        //Must be 720p
        hd44780.print(sevenTwentyP);

      } else if ((uint8_t)(rxBuffer[0] & 3) == 1 && rxBuffer[0]&CONEX_2E_HDTV_EN) {
        //Must be 480p
        hd44780.print(fourEightyP);

      } else {
        hd44780.print(fourEightyI);
      }

    }

    //Read the CPU and M/B temps
    //Try ADM1032
    if ((readSMBus(ADM1032_ADDRESS, ADM1032_CPU, &rxBuffer[0], 1) == 0 &&
         readSMBus(ADM1032_ADDRESS, ADM1032_MB, &rxBuffer[1], 1) == 0)  ||
        //If fails, its probably a 1.6. Read SMC instead.
        (readSMBus(SMC_ADDRESS, SMC_CPUTEMP, &rxBuffer[0], 1) == 0 &&
         readSMBus(SMC_ADDRESS, SMC_BOARDTEMP, &rxBuffer[1], 1) == 0)) {
      if (rxBuffer[0] < 200 && rxBuffer[1] < 200 && rxBuffer[0] > 0 && rxBuffer[1] > 0) {
#ifdef USE_FAHRENHEIT
        snprintf(lineBuffer, sizeof lineBuffer, tempDisplayF, (uint8_t)((float)rxBuffer[0] * 1.8 + 32.0), (char)223,
                 (uint8_t)((float)rxBuffer[1] * 1.8 + 32.0), (char)223);
#else
        snprintf(lineBuffer, sizeof lineBuffer, tempDisplayC, rxBuffer[0], (char)223, rxBuffer[1], (char)223);
#endif
        hd44780.setCursor(0, 3); //Write temperatures to LCD row 3
        hd44780.print(lineBuffer);
      }
      SMBusTimer = millis();
    }

  } else if (SPIState != SPI_WAIT) {
    SMBusTimer = millis();

  }
}

/*
   Function: Check if the SMBus/I2C bus is busy
   ----------------------------
     returns: 0 if busy is free, non zero if busy or still checking
*/
uint8_t i2cBusy() {
  if (digitalRead(i2c_sda) == 0 || digitalRead(i2c_scl) == 0) { //If either the data or clock line is low, the line must be busy
    i2cCheckCount = I2C_BUSY_CHECKS;
  } else {
    i2cCheckCount--; //Bus isn't busy, decrease check counter so we check multiple times to be sure.
  }
  return i2cCheckCount;
}

/*
   Function: Read the Xbox SMBus
   ----------------------------
     address: The address of the device on the SMBus
     command: The command to send to the device. Normally the register to read from
     rx: A pointer to a receive data buffer
     len: How many bytes to read
     returns: 0 on success, -1 on error.
*/
int8_t readSMBus(uint8_t address, uint8_t command, char* rx, uint8_t len) {
  Wire.beginTransmission(address);
  Wire.write(command);
  if (Wire.endTransmission(false) == 0) { //Needs to be false. Send I2c repeated start, dont release bus yet
    Wire.requestFrom(address, len);
    for (uint8_t i = 0; i < len; i++) {
      rx[i] = Wire.read();
    }
    return 0;
  } else {
    return -1;
  }

}

void completeCommand(int16_t* c) {
  *c = -1;
}

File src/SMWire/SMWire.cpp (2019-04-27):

/*
  TwoWire.cpp - TWI/I2C library for Wiring & Arduino
  Copyright (c) 2006 Nicholas Zambetti.  All right reserved.

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
  Modified 2012 by Todd Krein (todd@krein.org) to implement repeated starts
  Modified 2017 by Chuck Todd (ctodd@cableone.net) to correct Unconfigured Slave Mode reboot
*/

extern "C" {
  #include <stdlib.h>
  #include <string.h>
  #include <inttypes.h>
  #include "utility/twi.h"
}

#include "SMWire.h"

// Initialize Class Variables //////////////////////////////////////////////////

uint8_t TwoWire::rxBuffer[BUFFER_LENGTH];
uint8_t TwoWire::rxBufferIndex = 0;
uint8_t TwoWire::rxBufferLength = 0;

uint8_t TwoWire::txAddress = 0;
uint8_t TwoWire::txBuffer[BUFFER_LENGTH];
uint8_t TwoWire::txBufferIndex = 0;
uint8_t TwoWire::txBufferLength = 0;

uint8_t TwoWire::transmitting = 0;
void (*TwoWire::user_onRequest)(void);
void (*TwoWire::user_onReceive)(int);

// Constructors ////////////////////////////////////////////////////////////////

TwoWire::TwoWire()
{
}

// Public Methods //////////////////////////////////////////////////////////////

void TwoWire::begin(void)
{
  rxBufferIndex = 0;
  rxBufferLength = 0;

  txBufferIndex = 0;
  txBufferLength = 0;

  twi_init();
  twi_attachSlaveTxEvent(onRequestService); // default callback must exist
  twi_attachSlaveRxEvent(onReceiveService); // default callback must exist
}

void TwoWire::begin(uint8_t address)
{
  begin();
  twi_setAddress(address);
}

void TwoWire::begin(int address)
{
  begin((uint8_t)address);
}

void TwoWire::end(void)
{
  twi_disable();
}

void TwoWire::setClock(uint32_t clock)
{
  twi_setFrequency(clock);
}

uint8_t TwoWire::requestFrom(uint8_t address, uint8_t quantity, uint32_t iaddress, uint8_t isize, uint8_t sendStop)
{
  if (isize > 0) {
  // send internal address; this mode allows sending a repeated start to access
  // some devices' internal registers. This function is executed by the hardware
  // TWI module on other processors (for example Due's TWI_IADR and TWI_MMR registers)

  beginTransmission(address);

  // the maximum size of internal address is 3 bytes
  if (isize > 3){
    isize = 3;
  }

  // write internal register address - most significant byte first
  while (isize-- > 0)
    write((uint8_t)(iaddress >> (isize*8)));
  endTransmission(false);
  }

  // clamp to buffer length
  if(quantity > BUFFER_LENGTH){
    quantity = BUFFER_LENGTH;
  }
  // perform blocking read into buffer
  uint8_t read = twi_readFrom(address, rxBuffer, quantity, sendStop);
  // set rx buffer iterator vars
  rxBufferIndex = 0;
  rxBufferLength = read;

  return read;
}

uint8_t TwoWire::requestFrom(uint8_t address, uint8_t quantity, uint8_t sendStop) {
	return requestFrom((uint8_t)address, (uint8_t)quantity, (uint32_t)0, (uint8_t)0, (uint8_t)sendStop);
}

uint8_t TwoWire::requestFrom(uint8_t address, uint8_t quantity)
{
  return requestFrom((uint8_t)address, (uint8_t)quantity, (uint8_t)true);
}

uint8_t TwoWire::requestFrom(int address, int quantity)
{
  return requestFrom((uint8_t)address, (uint8_t)quantity, (uint8_t)true);
}

uint8_t TwoWire::requestFrom(int address, int quantity, int sendStop)
{
  return requestFrom((uint8_t)address, (uint8_t)quantity, (uint8_t)sendStop);
}

void TwoWire::beginTransmission(uint8_t address)
{
  // indicate that we are transmitting
  transmitting = 1;
  // set address of targeted slave
  txAddress = address;
  // reset tx buffer iterator vars
  txBufferIndex = 0;
  txBufferLength = 0;
}

void TwoWire::beginTransmission(int address)
{
  beginTransmission((uint8_t)address);
}

//
//	Originally, 'endTransmission' was an f(void) function.
//	It has been modified to take one parameter indicating
//	whether or not a STOP should be performed on the bus.
//	Calling endTransmission(false) allows a sketch to 
//	perform a repeated start. 
//
//	WARNING: Nothing in the library keeps track of whether
//	the bus tenure has been properly ended with a STOP. It
//	is very possible to leave the bus in a hung state if
//	no call to endTransmission(true) is made. Some I2C
//	devices will behave oddly if they do not see a STOP.
//
uint8_t TwoWire::endTransmission(uint8_t sendStop)
{
  // transmit buffer (blocking)
  uint8_t ret = twi_writeTo(txAddress, txBuffer, txBufferLength, 1, sendStop);
  // reset tx buffer iterator vars
  txBufferIndex = 0;
  txBufferLength = 0;
  // indicate that we are done transmitting
  transmitting = 0;
  return ret;
}

//	This provides backwards compatibility with the original
//	definition, and expected behaviour, of endTransmission
//
uint8_t TwoWire::endTransmission(void)
{
  return endTransmission(true);
}

// must be called in:
// slave tx event callback
// or after beginTransmission(address)
size_t TwoWire::write(uint8_t data)
{
  if(transmitting){
  // in master transmitter mode
    // don't bother if buffer is full
    if(txBufferLength >= BUFFER_LENGTH){
      setWriteError();
      return 0;
    }
    // put byte in tx buffer
    txBuffer[txBufferIndex] = data;
    ++txBufferIndex;
    // update amount in buffer   
    txBufferLength = txBufferIndex;
  }else{
  // in slave send mode
    // reply to master
    twi_transmit(&data, 1);
  }
  return 1;
}

// must be called in:
// slave tx event callback
// or after beginTransmission(address)
size_t TwoWire::write(const uint8_t *data, size_t quantity)
{
  if(transmitting){
  // in master transmitter mode
    for(size_t i = 0; i < quantity; ++i){
      write(data[i]);
    }
  }else{
  // in slave send mode
    // reply to master
    twi_transmit(data, quantity);
  }
  return quantity;
}

// must be called in:
// slave rx event callback
// or after requestFrom(address, numBytes)
int TwoWire::available(void)
{
  return rxBufferLength - rxBufferIndex;
}

// must be called in:
// slave rx event callback
// or after requestFrom(address, numBytes)
int TwoWire::read(void)
{
  int value = -1;
  
  // get each successive byte on each call
  if(rxBufferIndex < rxBufferLength){
    value = rxBuffer[rxBufferIndex];
    ++rxBufferIndex;
  }

  return value;
}

// must be called in:
// slave rx event callback
// or after requestFrom(address, numBytes)
int TwoWire::peek(void)
{
  int value = -1;
  
  if(rxBufferIndex < rxBufferLength){
    value = rxBuffer[rxBufferIndex];
  }

  return value;
}

void TwoWire::flush(void)
{
  // XXX: to be implemented.
}
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

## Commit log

2019-05-03 Fixes and additional info added
    [spi2par2019.ino, xeniumspi.h]
2019-05-17 Fixed 1.6 temp readout, added Conexant video resolution output
    [spi2par2019.ino]
2019-05-18 Added Programming and Install Instructions, typos fixed. 1.6 temp readout fixed
    [spi2par2019faithful.sch]
2019-09-01 Fixed PWM flickering issue
    [spi2par2019.ino]
2019-09-15 Fixed Fahrenheit display on non 1.6 versions
    [spi2par2019.ino]
2019-12-06 Added XeniumCursorHome and many bug fixes. Better stability during boot up
    [spi2par2019.ino, xeniumspi.h]
2020-07-01 Fix some compiler warnings and print bugs
    [spi2par2019.ino]
2021-06-07 CI: Update latest arduino CLI
